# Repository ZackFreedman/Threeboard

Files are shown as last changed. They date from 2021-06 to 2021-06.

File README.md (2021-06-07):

The littlest wireless macro pad! AWWWWW!!!
(c) 2021 Zack Freedman and Voidstar Lab. Licensed CC-BY-NC (credit me and don't sell it)
Built partially on stream (like comment and subscribe baby) so it might suck.

Print one of each STL. The faceplate and the middle piece with the stupid name need supports, the baseplate don't.

You'll also need:
* An Adafruit NRF52 Feather* - https://amzn.to/3inlreo
* 3x Cherry-sized keyswitches - https://amzn.to/3pqnakz
* 3x keycaps of your choice (NSFW) - https://amzn.to/3v0asKp 
* A 128x32 SSD1306 OLED module - https://amzn.to/3z47vvA
* A 750mAh Li-ion 14500 battery - https://amzn.to/3gfcfG7
* 2x AA battery clips - https://www.digikey.com/en/products/detail/mpd-memory-protection-devices/BK-92/2079904
* 4x 10mm and 2x 8mm M2.5 screws - https://amzn.to/3fZuJM1
* 4x 8mm rubber feet - https://amzn.to/2RrHw04
* Some wire
* Some hot glue

Assembly:
* Print everything ya dingus
* Stick the switches in the switch holes
* Jam the battery clips into their battery clip slots
* Use a soldering iron set to 210C or something to melt the plastic around the battery clips to fuse them in place
* Wire one pin of each switch together
* Wire those switches to one of the battery clips. This is now the GND clip.
* Solder a wire to the other clip, that's now the VBAT clip
* Solder a wire to the other pin of each switch
* Solder wires to the OLED and glue it into position in the faceplate
* Solder the OLED GND wire to the GND clip. It's kinda overloaded, I know
* Solder the GND wire to the GND pad on the Feather
* Solder the VBAT wire to the VBAT pad
* Solder the left, center, and right switch wires to pins 16, 15, and 7
* Solder the OLED's SDA, SCL, and 3V to the corresponding pads
* Screw it together. The 8mm screws are in the bottom front corners.
* Stick the feet on the bottom. Or the side, or the top. You're the boss.
* Charge that battery and load the code
* Go to patreon.com/zackfreedman and give me all your money

\*you should probably buy this directly from Adafruit

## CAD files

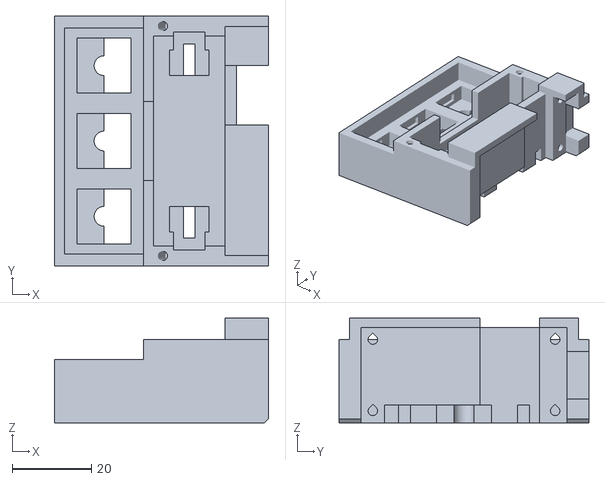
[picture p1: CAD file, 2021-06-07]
Models/Something that rhymes with Aceplate.stl
54.0 x 63.0 x 26.4

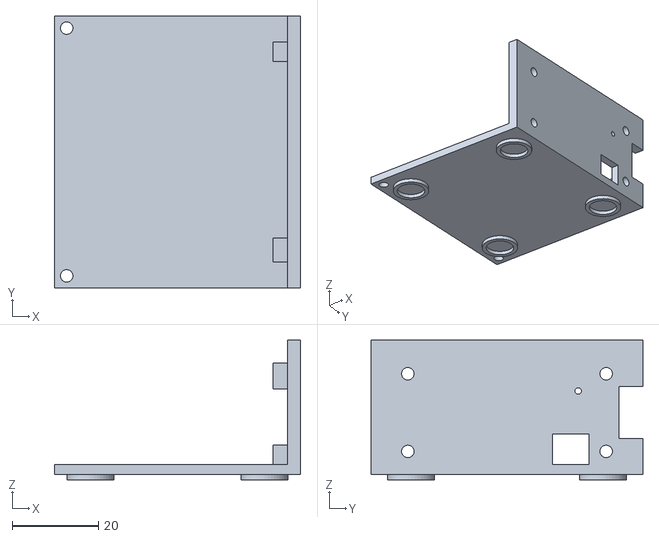
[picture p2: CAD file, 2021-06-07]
Models/Baseplate.stl
57.0 x 63.0 x 32.4

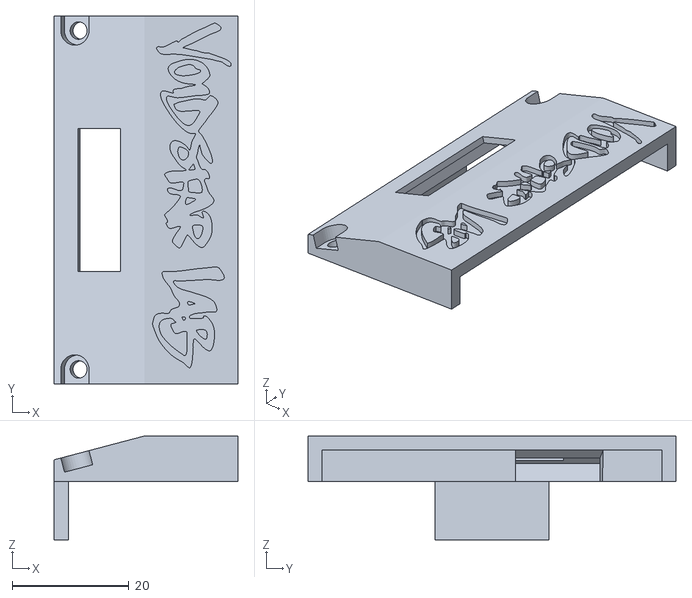
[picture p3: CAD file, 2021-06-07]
Models/Faceplate.stl
31.5 x 63.0 x 17.8

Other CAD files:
Models/Threeboard.f3d

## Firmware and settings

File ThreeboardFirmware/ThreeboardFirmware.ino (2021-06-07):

//
// OneBitDisplay library simple demo
//
// Demonstrates how to initialize and use a few functions of the library
// If your MCU has enough RAM, enable the backbuffer to see a demonstration
// of the speed difference between drawing directly on the display versus
// deferred rendering, followed by a "dump" of the memory to the display
//
#include <OneBitDisplay.h>
#include <bluefruit.h>
#include <Bounce2.h>

BLEDis bledis;
BLEHidAdafruit blehid;

// if your system doesn't have enough RAM for a back buffer, comment out
// this line (e.g. ATtiny85)
#define USE_BACKBUFFER

#ifdef USE_BACKBUFFER
static uint8_t ucBackBuffer[1024];
#else
static uint8_t *ucBackBuffer = NULL;
#endif

int leftButtonPin = 16;
int midButtonPin = 15;
int rightButtonPin = 7;

Bounce leftButton = Bounce();
Bounce midButton = Bounce();
Bounce rightButton = Bounce();

bool hasKeyPressed;

// Use -1 for the Wire library default pins
// or specify the pin numbers to use with the Wire library or bit banging on any GPIO pins
// These are the pin numbers for the M5Stack Atom Grove port I2C (reversed SDA/SCL for straight through wiring)
#define SDA_PIN 2
#define SCL_PIN 3
// Set this to -1 to disable or the GPIO pin number connected to the reset
// line of your display if it requires an external reset
#define RESET_PIN -1
// let OneBitDisplay figure out the display address
#define OLED_ADDR -1
// don't rotate the display
#define FLIP180 0
// don't invert the display
#define INVERT 0
// Bit-Bang the I2C bus
#define USE_HW_I2C 1

// Change these if you're using a different OLED display
#define MY_OLED OLED_128x32
#define OLED_WIDTH 128
#define OLED_HEIGHT 32
//#define MY_OLED OLED_64x32
//#define OLED_WIDTH 64
//#define OLED_HEIGHT 32

OBDISP obd;

uint8_t keycode7[6] = { 0x5F };
uint8_t keycode8[6] = { 0x60 };
uint8_t keycode9[6] = { 0x61 };

void setup() {
  delay(5000);

  pinMode(leftButtonPin, INPUT_PULLUP);
  pinMode(midButtonPin, INPUT_PULLUP);
  pinMode(rightButtonPin, INPUT_PULLUP);

  leftButton.attach(leftButtonPin);
  leftButton.interval(5); // interval in ms

  midButton.attach(midButtonPin);
  midButton.interval(5); // interval in ms

  rightButton.attach(rightButtonPin);
  rightButton.interval(5); // interval in ms

  Bluefruit.begin();
  Bluefruit.setTxPower(4);    // Check bluefruit.h for supported values
  Bluefruit.setName("MicroMacro");

  // Configure and Start Device Information Service
  bledis.setManufacturer("Voidstar Lab");
  bledis.setModel("Micro Macro Pad");
  bledis.begin();

  blehid.begin();

  blehid.setKeyboardLedCallback(set_keyboard_led);

  int rc;
  // The I2C SDA/SCL pins set to -1 means to use the default Wire library
  // If pins were specified, they would be bit-banged in software
  // This isn't inferior to hw I2C and in fact allows you to go faster on certain CPUs
  // The reset pin is optional and I've only seen it needed on larger OLEDs (2.4")
  //    that can be configured as either SPI or I2C
  //
  // obdI2CInit(OBDISP *, type, oled_addr, rotate180, invert, bWire, SDA_PIN, SCL_PIN, RESET_PIN, speed)

  rc = obdI2CInit(&obd, MY_OLED, OLED_ADDR, FLIP180, INVERT, USE_HW_I2C, SDA_PIN, SCL_PIN, RESET_PIN, 800000L); // use standard I2C bus at 400Khz
  if (rc != OLED_NOT_FOUND)
  {
    char *msgs[] = {(char *)"SSD1306 @ 0x3C", (char *)"SSD1306 @ 0x3D", (char *)"SH1106 @ 0x3C", (char *)"SH1106 @ 0x3D"};
    obdFill(&obd, 0, 1);
    obdWriteString(&obd, 0, 0, 0, msgs[rc], FONT_8x8, 0, 1);
    obdSetBackBuffer(&obd, ucBackBuffer);
    delay(2000);
  }

  startAdv();
} /* setup() */

void loop() {
  // put your main code here, to run repeatedly:
  leftButton.update();
  midButton.update();
  rightButton.update();

  bool leftButtonPressed = leftButton.fell();
  bool midButtonPressed = midButton.fell();
  bool rightButtonPressed = rightButton.fell();

  int i, x, y;
  char szTemp[32];
  unsigned long ms;

  if ( hasKeyPressed )
  {
    hasKeyPressed = false;
    blehid.keyRelease();

    // Delay a bit after a report
    delay(5);
  }

  if (leftButtonPressed) {
    blehid.keyboardReport(0, keycode7);
    hasKeyPressed = true;
    delay(5);
  }

  if (midButtonPressed) {
    blehid.keyboardReport(0, keycode8);
    hasKeyPressed = true;
    delay(5);
  }

  if (rightButtonPressed) {
    blehid.keyboardReport(0, keycode9);
    hasKeyPressed = true;
    delay(5);
  }

  /*
    obdFill(&obd, 0x0, 1);
    obdWriteString(&obd, 0, 28, 0, (char *)"OLED Demo", FONT_8x8, 0, 1);
    obdWriteString(&obd, 0, 0, 1, (char *)"Written by Larry Bank", FONT_6x8, 1, 1);
    obdWriteString(&obd, 0, 0, 3, (char *)"**Demo**", FONT_16x32, 0, 1);
    delay(2000);

    // Pixel and line functions won't work without a back buffer
    #ifdef USE_BACKBUFFER
    obdFill(&obd, 0, 1);
    obdWriteString(&obd, 0, 0, 0, (char *)"Backbuffer Test", FONT_8x8, 0, 1);
    obdWriteString(&obd, 0, 0, 1, (char *)"3000 Random dots", FONT_8x8, 0, 1);
    delay(2000);
    obdFill(&obd, 0, 1);
    ms = millis();
    for (i = 0; i < 3000; i++)
    {
      x = random(OLED_WIDTH);
      y = random(OLED_HEIGHT);
      obdSetPixel(&obd, x, y, 1, 1);
    }
    ms = millis() - ms;
    sprintf(szTemp, "%dms", (int)ms);
    obdWriteString(&obd, 0, 0, 0, szTemp, FONT_8x8, 0, 1);
    obdWriteString(&obd, 0, 0, 1, (char *)"Without backbuffer", FONT_6x8, 0, 1);
    delay(2000);
    obdFill(&obd, 0, 1);
    ms = millis();
    for (i = 0; i < 3000; i++)
    {
      x = random(OLED_WIDTH);
      y = random(OLED_HEIGHT);
      obdSetPixel(&obd, x, y, 1, 0);
    }
    obdDumpBuffer(&obd, NULL);
    ms = millis() - ms;
    sprintf(szTemp, "%dms", (int)ms);
    obdWriteString(&obd, 0, 0, 0, szTemp, FONT_8x8, 0, 1);
    obdWriteString(&obd, 0, 0, 1, (char *)"With backbuffer", FONT_6x8, 0, 1);
    delay(2000);
    obdFill(&obd, 0, 1);
    obdWriteString(&obd, 0, 0, 0, (char *)"Backbuffer Test", FONT_8x8, 0, 1);
    obdWriteString(&obd, 0, 0, 1, (char *)"96 lines", FONT_8x8, 0, 1);
    delay(2000);
    ms = millis();
    for (x = 0; x < OLED_WIDTH - 1; x += 2)
    {
      obdDrawLine(&obd, x, 0, OLED_WIDTH - x, OLED_HEIGHT - 1, 1, 1);
    }
    for (y = 0; y < OLED_HEIGHT - 1; y += 2)
    {
      obdDrawLine(&obd, OLED_WIDTH - 1, y, 0, OLED_HEIGHT - 1 - y, 1, 1);
    }
    ms = millis() - ms;
    sprintf(szTemp, "%dms", (int)ms);
    obdWriteString(&obd, 0, 0, 0, szTemp, FONT_8x8, 0, 1);
    obdWriteString(&obd, 0, 0, 1, (char *)"Without backbuffer", FONT_6x8, 0, 1);
    delay(2000);
    obdFill(&obd, 0, 1);
    ms = millis();
    for (x = 0; x < OLED_WIDTH - 1; x += 2)
    {
      obdDrawLine(&obd, x, 0, OLED_WIDTH - 1 - x, OLED_HEIGHT - 1, 1, 0);
    }
    for (y = 0; y < OLED_HEIGHT - 1; y += 2)
    {
      obdDrawLine(&obd, OLED_WIDTH - 1, y, 0, OLED_HEIGHT - 1 - y, 1, 0);
    }
    obdDumpBuffer(&obd, ucBackBuffer);
    ms = millis() - ms;
    sprintf(szTemp, "%dms", (int)ms);
    obdWriteString(&obd, 0, 0, 0, szTemp, FONT_8x8, 0, 1);
    obdWriteString(&obd, 0, 0, 1, (char *)"With backbuffer", FONT_6x8, 0, 1);
    delay(2000);
    #endif
  */
} /* loop() */

void startAdv(void)
{
  // Advertising packet
  Bluefruit.Advertising.addFlags(BLE_GAP_ADV_FLAGS_LE_ONLY_GENERAL_DISC_MODE);
  Bluefruit.Advertising.addTxPower();
  Bluefruit.Advertising.addAppearance(BLE_APPEARANCE_HID_KEYBOARD);

  // Include BLE HID service
  Bluefruit.Advertising.addService(blehid);

  // There is enough room for the dev name in the advertising packet
  Bluefruit.Advertising.addName();

  /* Start Advertising
     - Enable auto advertising if disconnected
     - Interval:  fast mode = 20 ms, slow mode = 152.5 ms
     - Timeout for fast mode is 30 seconds
     - Start(timeout) with timeout = 0 will advertise forever (until connected)

     For recommended advertising interval
     https://developer.apple.com/library/content/qa/qa1931/_index.html
  */
  Bluefruit.Advertising.restartOnDisconnect(true);
  Bluefruit.Advertising.setInterval(32, 244);    // in unit of 0.625 ms
  Bluefruit.Advertising.setFastTimeout(30);      // number of seconds in fast mode
  Bluefruit.Advertising.start(0);                // 0 = Don't stop advertising after n seconds
}

/**
   Callback invoked when received Set LED from central.
   Must be set previously with setKeyboardLedCallback()

   The LED bit map is as follows: (also defined by KEYBOARD_LED_* )
      Kana (4) | Compose (3) | ScrollLock (2) | CapsLock (1) | Numlock (0)
*/
void set_keyboard_led(uint16_t conn_handle, uint8_t led_bitmap)
{
  (void) conn_handle;

  // light up Red Led if any bits is set
  if ( led_bitmap )
  {
    ledOn( LED_RED );
  }
  else
  {
    ledOff( LED_RED );
  }
}
